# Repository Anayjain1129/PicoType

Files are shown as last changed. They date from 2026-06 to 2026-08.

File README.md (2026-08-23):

# PicoType 
WhatsApp Image 2026-08-19 at 5 43 49 AM













## Zine Page


## Physically Built










### What is this project? 
This is a keyboard made from scratch made by a teenage, made from PCB, CAD to firmware everything! basically this is a keyboard which helps you type things and uses RP2040 and and it sounds thockyy!! 

### How to use it?
1. Assemble the PCB by soldering the Raspberry pi pico, switches and encoder and the OLED display which is on the numpad pcb
2. Plug the MCU (raspberry pi pico) with your computer and make sure the boot button on the MCU is pressed down while you are plugging in the MCU
3. Drag and drop the .uf2 file in the MCU of Raspberry Pi Pico 
4. Do the same things with Xiao rp2040
5. wolla you have everything working!! 

### Why did i made this? 
I made this to learn new skills and learn more about PCBs and do ALOT of CAD the case/CAD of this project took so much time! and the case makes it looks so much awesome! and i have made a separate numpad which can alsop be used as a macropad, you can use it as a full sized keyboard or just as a ANSI-75 Keyboard with a small macropad on your desk! the numpad also have a keychian holder so you can carry it easily too! 

# Features
- EC11 Rotary Encoder - For Volume, Brightness etc
- Oled screen -  To play gifs and notifications
- ANSI-75 Layout
- Raspberry Pi Pico
- Custom Layout
- QMK firmware
- Awesome CAD/cool case design
- Uses RP2040

## Schematics 



## PCB



## 3d PCB



# Case
## Top






## Middle Plate






## Bottom








# 3d view of all parts together







# BOM
| # | Item | Description | Quantity | URL | Total Price (INR) | Total Price (USD) |
|---|---|---|---|-----|:---:|:---:|
| 1 | Numpad PCB | PCB for the Numpad | 5 | N/A | ₹1,845 | $19.53 |
| 2 | PicoType PCB | PCB for the PicoType | 5 | N/A | ₹5,175 | $54.67 |
| 3 | 0.91 Inch OLED | OLED display | 1 | [Link](https://robu.in/product/blue-oled-display-module/) | ₹151 | $1.60 |
| 4 | Switches | The mechanical switches | 11 | [Link](https://neomacro.in/products/gateron-ef-cedar) | ₹1,980 | $20.92 |
| 5 | Rotary Encoder | The Rotary Encoder which can | 1 | [Link](https://robu.in/product/hongyan-ec11h-7ce20p1zy15f7-rotary-encoder-with-push-button-switch-vertical-plug-in-5-pin/) | ₹55 | $0.58 |
| 6 | XIAO RP2040 | MCU to be used for Numpad | 1 | [Link](https://robocraze.com/products/seeed-studio-seeeduino-xiao-samd21-arduino-compatible-board) | ₹645 | $6.81 |
| 7 | Raspberry Pi Pico | MCU to be used for PicoType | 1 | [Link](https://robocraze.com/products/raspberry-pi-pico-h-pico-with-headers-soldered) | ₹525 | $5.55 |
| 8 | Keycaps | Keycaps to put on top of switches | 9 | Self Sourced | N/A | N/A |
| 9 | Case | To put everything together | 1 | Print-Legion | N/A | N/A |
| 10 | Magnets | Magnets to hold the case together | N/A | Self Sourced | N/A | N/A |
| | | | | **Total Cost** | **₹10,376** | **$109.66** |

# Demo Link
https://youtu.be/6P1yl1J2G_w?si=dBfJKUdtHREIIz_N

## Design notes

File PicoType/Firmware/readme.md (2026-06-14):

# picotype

picotype

*A short description of the keyboard/project*

* Keyboard Maintainer: [Anayjain1129](https://github.com/Anayjain1129)
* Hardware Supported: *The PCBs, controllers supported*
* Hardware Availability: *Links to where you can find this hardware*

Make example for this keyboard (after setting up your build environment):

    make picotype:default

Flashing example for this keyboard:

    make picotype:default:flash

See the [build environment setup](https://docs.qmk.fm/#/getting_started_build_tools) and the [make instructions](https://docs.qmk.fm/#/getting_started_make_guide) for more information. Brand new to QMK? Start with our [Complete Newbs Guide](https://docs.qmk.fm/#/newbs).

## Bootloader

Enter the bootloader in 3 ways:

* **Bootmagic reset**: Hold down the key at (0,0) in the matrix (usually the top left key or Escape) and plug in the keyboard
* **Physical reset button**: Briefly press the button on the back of the PCB - some may have pads you must short instead
* **Keycode in layout**: Press the key mapped to `QK_BOOT` if it is available

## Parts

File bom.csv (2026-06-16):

Item | Description | Quantity | URL | Total Price(INR) | Total Price (USD)
Numpad PCB | PCB for the Numpad | 5 | N/A | 1845 | $19.53
PicoType PCB | PCB for the PicoType | 5 | N/A | 5175 | $54.67
0.91 Inch OLED | OLED display | 1 | https://robu.in/product/blue-oled-display-module/ | 151 | $1.60
Switches | The mechanical switces | 11 | https://neomacro.in/products/gateron-ef-cedar | 1980 | $20.92
Rotary Encoder | The Rotary Encode which can | 1 | https://robu.in/product/hongyan-ec11h-7ce20p1zy15f7-rotary-encoder-with-push-button-switch-vertical-plug-in-5-pin/ | 55 | $0.58
XIAO RP2040 | MCU which is fonan be used for numpad | 1 | https://robocraze.com/products/seeed-studio-seeeduino-xiao-samd21-arduino-compatible-board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 | 645 | $6.81
Raspberry Pi Pico | MCU which is fonan be used for PicoType | 1 | https://robocraze.com/products/raspberry-pi-pico-h-pico-with-headers-soldered?_pos=8&_sid=71184d8c2&_ss=r | 525 | $5.55
Keycaps | Keycaps to put on top of switches | 9 | Self Sourced | N/A | N/A
Case | To put eveything together | 1 | Print-Legion | N/A | N/A
Magnets | magnets to hold the case together | N/A | Self Sourced | N/A | N/A
 |  |  | Total Cost: | 10,376 | $109.66

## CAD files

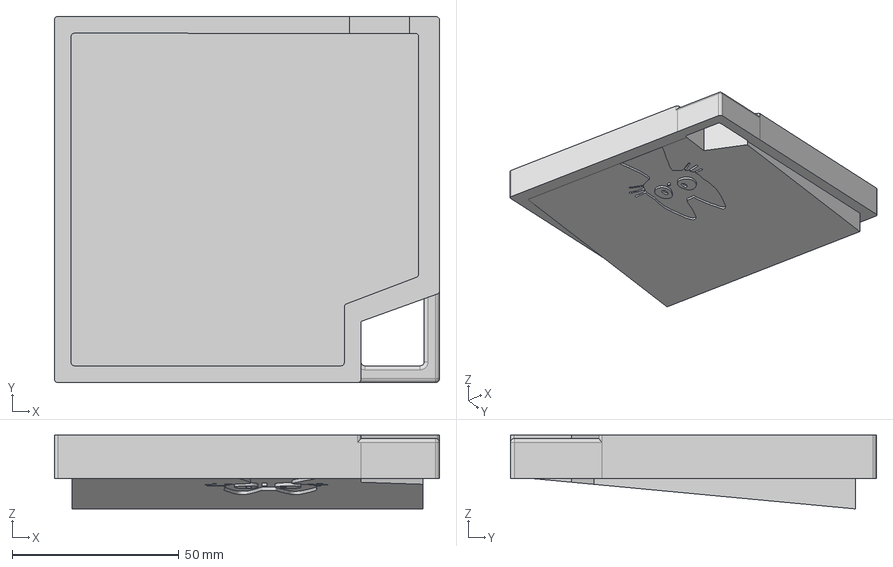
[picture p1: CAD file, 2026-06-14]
numpad/CAD/bottom/bottom.step
115.3 x 109.6 x 22.1 mm

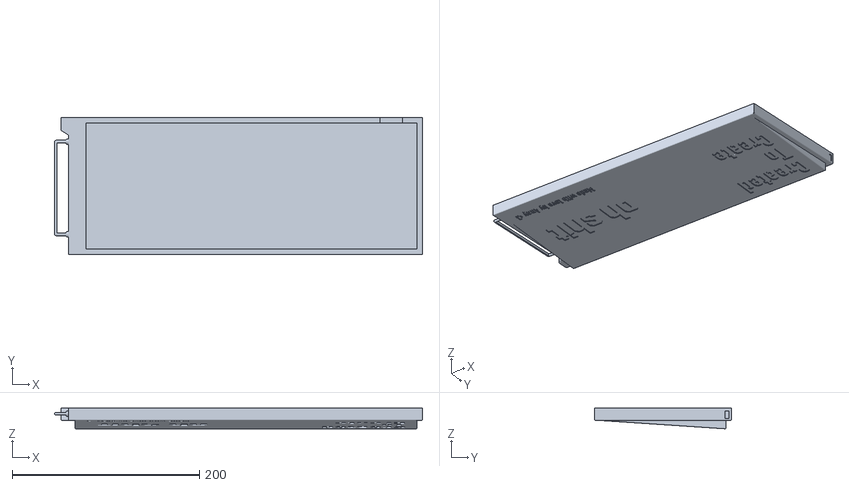
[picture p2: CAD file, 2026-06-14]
PicoType/CAD/bottom/bottom.stl
393.0 x 146.7 x 22.0

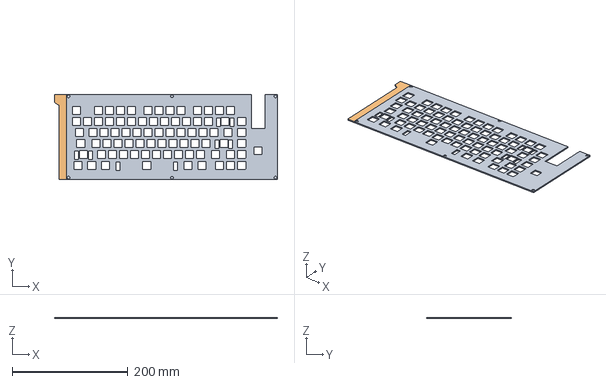
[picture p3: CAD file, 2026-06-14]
PicoType/CAD/middle/middle.step
386.0 x 147.3 x 2.00 mm

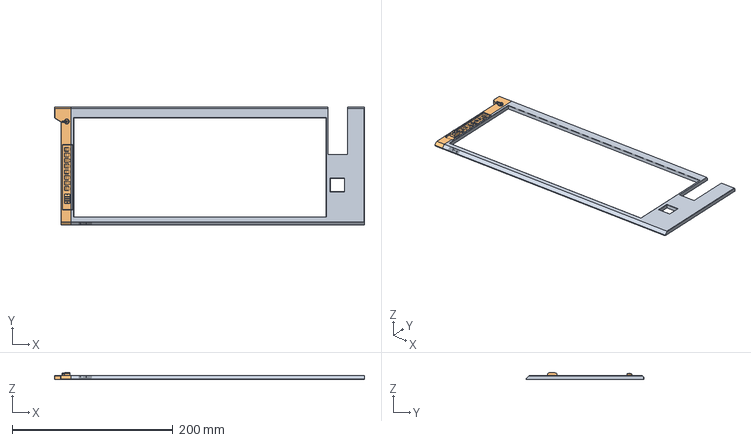
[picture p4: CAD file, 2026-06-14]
PicoType/CAD/top/top.step
386.0 x 147.3 x 9.00 mm

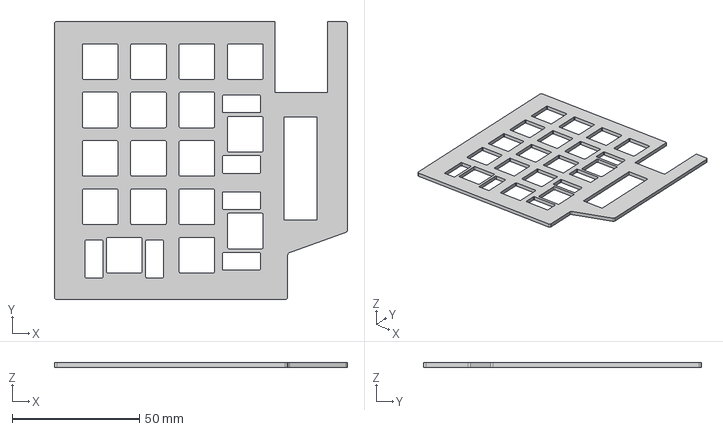
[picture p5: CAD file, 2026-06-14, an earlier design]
numpad/CAD/middle/middle.step
115.3 x 109.6 x 2.00 mm

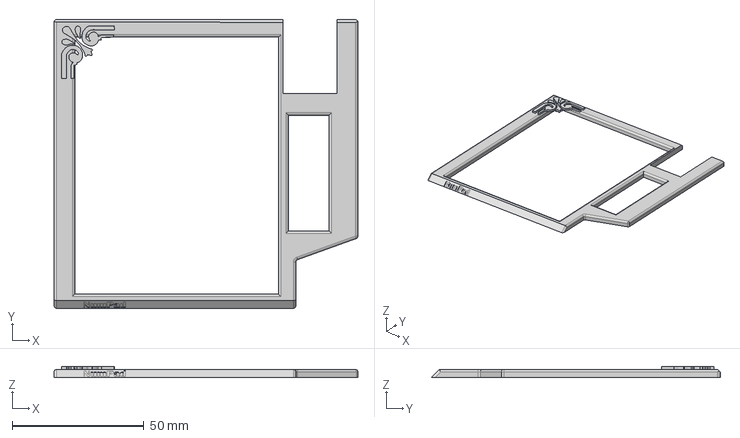
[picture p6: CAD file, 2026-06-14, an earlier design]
numpad/CAD/top/top.step
115.3 x 109.6 x 4.00 mm

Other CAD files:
PicoType/CAD/bottom/bttom.step
PicoType/Production/CAD/bttom.step
Assembly/keyboard.f3z
Assembly/numpad.f3z
PicoType/CAD/bottom/bottom.f3d
PicoType/CAD/middle/middle.f3d
PicoType/CAD/middle/middle.stl
PicoType/CAD/top/top.f3d
PicoType/CAD/top/top.stl
PicoType/Production/CAD/middle.stl
PicoType/Production/CAD/top.stl
numpad/CAD/bottom/bottom.f3d
numpad/CAD/bottom/bottom.stl
numpad/CAD/middle/middle.f3d
numpad/CAD/middle/middle.stl
numpad/CAD/top/top.f3d
numpad/CAD/top/top.stl
numpad/Production/CAD/bottom.stl
numpad/Production/CAD/middle.stl
numpad/Production/CAD/top.stl

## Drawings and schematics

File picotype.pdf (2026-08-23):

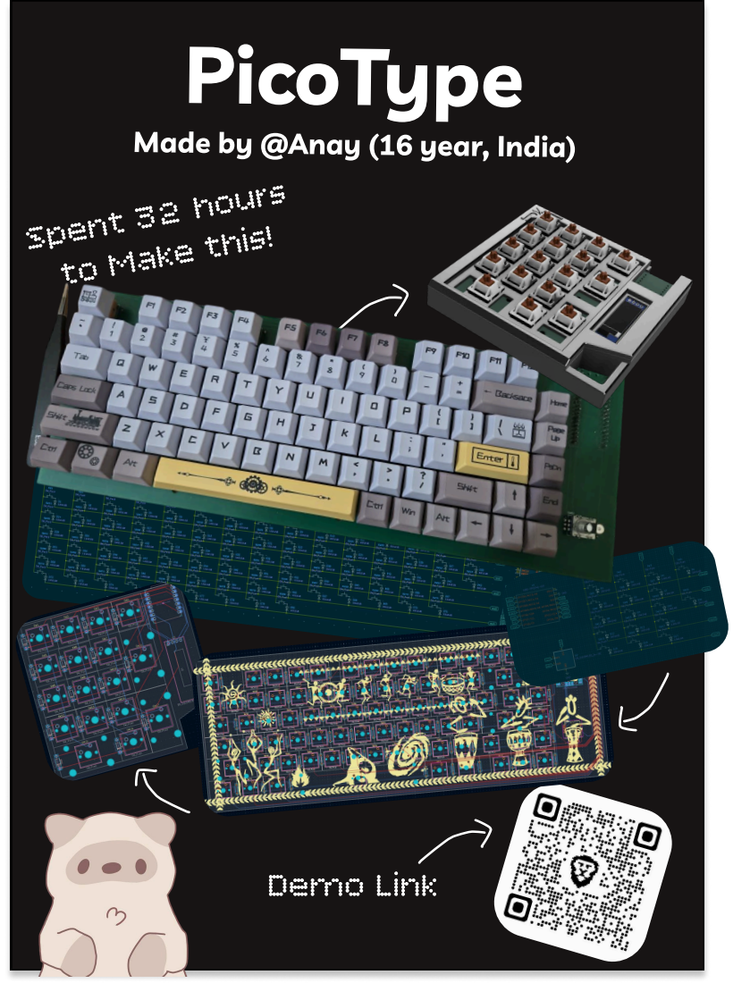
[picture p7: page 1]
Spent 32 hours; PicoType; Demo Link

Made by @Anay (16 year, India)

to Make this!

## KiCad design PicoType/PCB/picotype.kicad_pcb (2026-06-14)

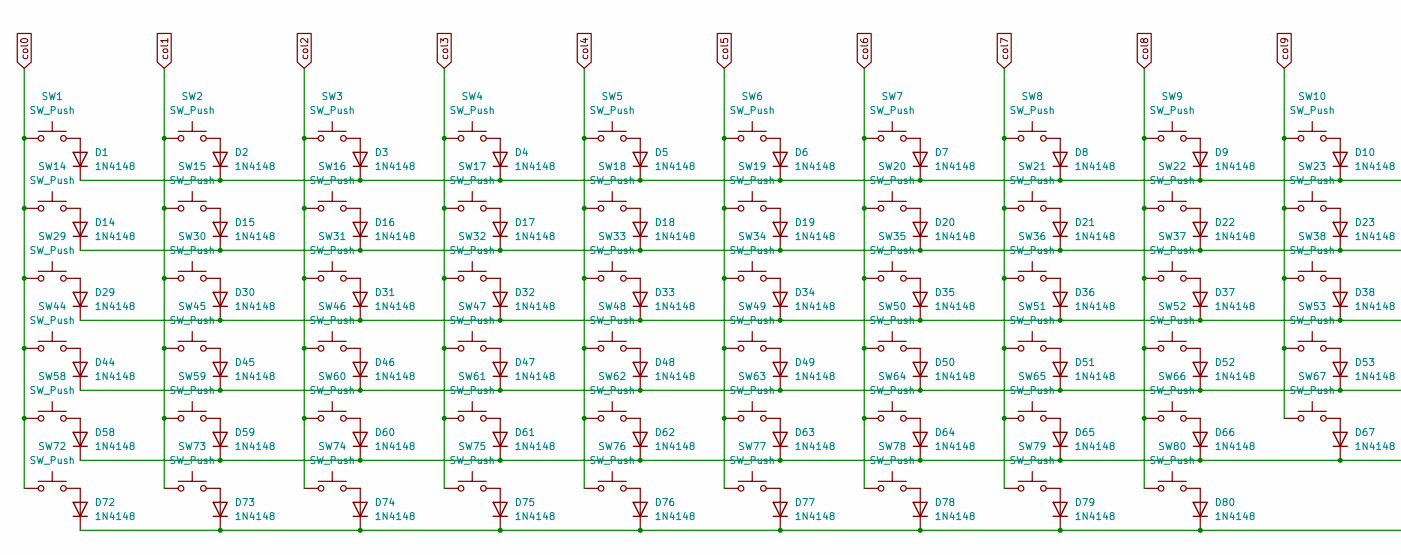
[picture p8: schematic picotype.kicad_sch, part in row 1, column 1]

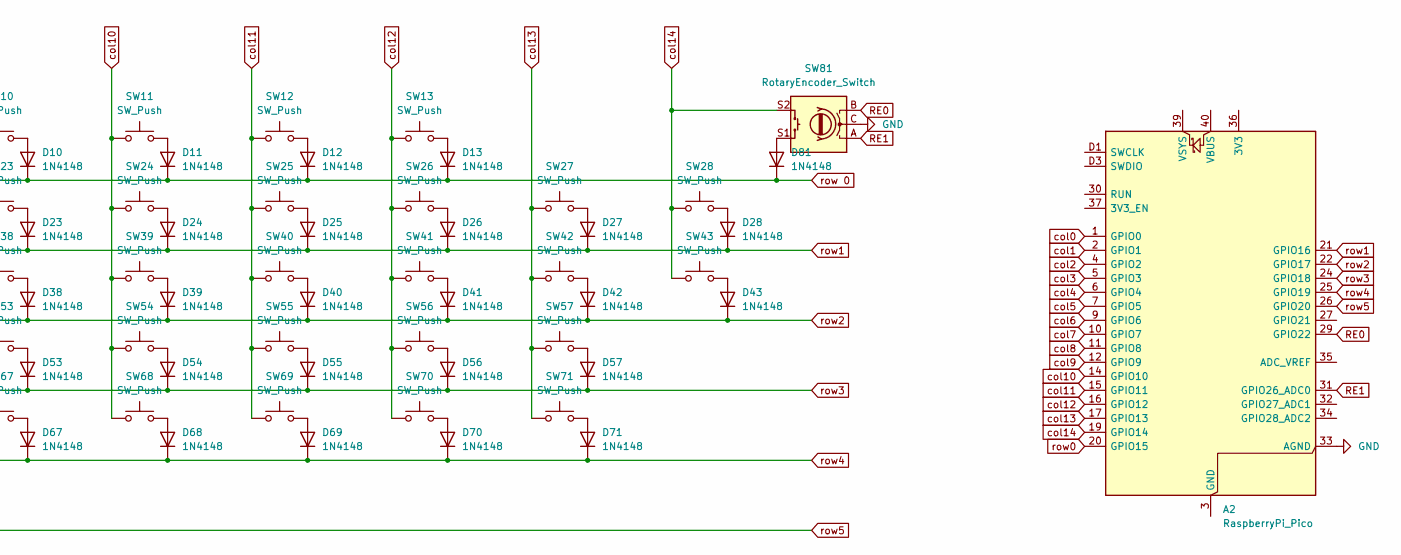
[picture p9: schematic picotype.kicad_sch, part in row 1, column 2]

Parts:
A2: RaspberryPi_Pico; RaspberryPi_Pico_SMD_HandSolder
D1, D2, D3, D4, D5, D6, D7, D8, D9, D10, D11, D12, D13, D14, D15, D16, D17, D18, D19, D20, D21, D22, D23, D24, D25, D26, D27, D28, D29, D30, D31, D32, D33, D34, D35, D36, D37, D38, D39, D40, D41, D42, D43, D44, D45, D46, D47, D48, D49, D50, D51, D52, D53, D54, D55, D56, D57, D58, D59, D60, D61, D62, D63, D64, D65, D66, D67, D68, D69, D70, D71, D72, D73, D74, D75, D76, D77, D78, D79, D80, D81: 1N4148; D_DO-35_SOD27_P7.62mm_Horizontal
SW1, SW2, SW3, SW4, SW5, SW6, SW7, SW8, SW9, SW10, SW11, SW12, SW13, SW14, SW15, SW16, SW17, SW18, SW19, SW20, SW21, SW22, SW23, SW24, SW25, SW26, SW28, SW30, SW31, SW32, SW33, SW34, SW35, SW36, SW37, SW38, SW39, SW40, SW41, SW43, SW45, SW46, SW47, SW48, SW49, SW50, SW51, SW52, SW53, SW54, SW55, SW57, SW59, SW60, SW61, SW62, SW63, SW64, SW65, SW66, SW67, SW68, SW70, SW71, SW78, SW79, SW80: SW_Push; SW_Cherry_MX_1.00u_PCB
SW27: SW_Push; SW_Cherry_MX_2.00u_PCB
SW29, SW42: SW_Push; SW_Cherry_MX_1.50u_PCB
SW44, SW69: SW_Push; SW_Cherry_MX_1.75u_PCB
SW56, SW58: SW_Push; SW_Cherry_MX_2.25u_PCB
SW72, SW73, SW74, SW76, SW77: SW_Push; SW_Cherry_MX_1.25u_PCB
SW75: SW_Push; SW_Cherry_MX_6.25u_PCB
SW81: RotaryEncoder_Switch; RotaryEncoder_Alps_EC12E-Switch_Vertical_H20mm_CircularMoun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

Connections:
GND: A2.33 (AGND), SW81.C
unnamed: A2.3 (GND), A2.8 (GND), A2.13 (GND), A2.18 (GND), A2.23 (GND), A2.28 (GND), A2.38 (GND), A2.D2 (GND)
unnamed: D1.2 (A), SW1.2
unnamed: D2.2 (A), SW2.2
unnamed: D3.2 (A), SW3.2
unnamed: D4.2 (A), SW4.2
unnamed: D5.2 (A), SW5.2
unnamed: D6.2 (A), SW6.2
unnamed: D7.2 (A), SW7.2
unnamed: D8.2 (A), SW8.2
unnamed: D9.2 (A), SW9.2
unnamed: D10.2 (A), SW10.2
unnamed: D11.2 (A), SW11.2
unnamed: D12.2 (A), SW12.2
unnamed: D13.2 (A), SW13.2
unnamed: D14.2 (A), SW14.2
unnamed: D15.2 (A), SW15.2
unnamed: D16.2 (A), SW16.2
unnamed: D17.2 (A), SW17.2
unnamed: D18.2 (A), SW18.2
unnamed: D19.2 (A), SW19.2
unnamed: D20.2 (A), SW20.2
unnamed: D21.2 (A), SW21.2
unnamed: D22.2 (A), SW22.2
unnamed: D23.2 (A), SW23.2
unnamed: D24.2 (A), SW24.2
unnamed: D25.2 (A), SW25.2
unnamed: D26.2 (A), SW26.2
unnamed: D27.2 (A), SW27.2
unnamed: D28.2 (A), SW28.2
unnamed: D29.2 (A), SW29.2
unnamed: D30.2 (A), SW30.2
unnamed: D31.2 (A), SW31.2
unnamed: D32.2 (A), SW32.2
unnamed: D33.2 (A), SW33.2
unnamed: D34.2 (A), SW34.2
unnamed: D35.2 (A), SW35.2
unnamed: D36.2 (A), SW36.2
unnamed: D37.2 (A), SW37.2
unnamed: D38.2 (A), SW38.2
unnamed: D39.2 (A), SW39.2
unnamed: D40.2 (A), SW40.2
unnamed: D41.2 (A), SW41.2
unnamed: D42.2 (A), SW42.2
unnamed: D43.2 (A), SW43.2
unnamed: D44.2 (A), SW44.2
unnamed: D45.2 (A), SW45.2
unnamed: D46.2 (A), SW46.2
unnamed: D47.2 (A), SW47.2
unnamed: D48.2 (A), SW48.2
unnamed: D49.2 (A), SW49.2
unnamed: D50.2 (A), SW50.2
unnamed: D51.2 (A), SW51.2
unnamed: D52.2 (A), SW52.2
unnamed: D53.2 (A), SW53.2
unnamed: D54.2 (A), SW54.2
unnamed: D55.2 (A), SW55.2
unnamed: D56.2 (A), SW56.2
unnamed: D57.2 (A), SW57.2
unnamed: D58.2 (A), SW58.2
unnamed: D59.2 (A), SW59.2
unnamed: D60.2 (A), SW60.2
unnamed: D61.2 (A), SW61.2
unnamed: D62.2 (A), SW62.2
unnamed: D63.2 (A), SW63.2
unnamed: D64.2 (A), SW64.2
unnamed: D65.2 (A), SW65.2
unnamed: D66.2 (A), SW66.2
unnamed: D67.2 (A), SW67.2
unnamed: D68.2 (A), SW68.2
unnamed: D69.2 (A), SW69.2
unnamed: D70.2 (A), SW70.2
unnamed: D71.2 (A), SW71.2
unnamed: D72.2 (A), SW72.2
unnamed: D73.2 (A), SW73.2
unnamed: D74.2 (A), SW74.2
unnamed: D75.2 (A), SW75.2
unnamed: D76.2 (A), SW76.2
unnamed: D77.2 (A), SW77.2
unnamed: D78.2 (A), SW78.2
unnamed: D79.2 (A), SW79.2
unnamed: D80.2 (A), SW80.2
unnamed: D81.2 (A), SW81.S1
RE0: A2.29 (GPIO22), SW81.B
RE1: A2.31 (GPIO26_ADC0), SW81.A
col0: A2.1 (GPIO0), SW1.1, SW14.1, SW29.1, SW44.1, SW58.1, SW72.1
col1: A2.2 (GPIO1), SW2.1, SW15.1, SW30.1, SW45.1, SW59.1, SW73.1
col2: A2.4 (GPIO2), SW3.1, SW16.1, SW31.1, SW46.1, SW60.1, SW74.1
col3: A2.5 (GPIO3), SW4.1, SW17.1, SW32.1, SW47.1, SW61.1, SW75.1
col4: A2.6 (GPIO4), SW5.1, SW18.1, SW33.1, SW48.1, SW62.1, SW76.1
col5: A2.7 (GPIO5), SW6.1, SW19.1, SW34.1, SW49.1, SW63.1, SW77.1
col6: A2.9 (GPIO6), SW7.1, SW20.1, SW35.1, SW50.1, SW64.1, SW78.1
col7: A2.10 (GPIO7), SW8.1, SW21.1, SW36.1, SW51.1, SW65.1, SW79.1
col8: A2.11 (GPIO8), SW9.1, SW22.1, SW37.1, SW52.1, SW66.1, SW80.1
col9: A2.12 (GPIO9), SW10.1, SW23.1, SW38.1, SW53.1, SW67.1
col10: A2.14 (GPIO10), SW11.1, SW24.1, SW39.1, SW54.1, SW68.1
col11: A2.15 (GPIO11), SW12.1, SW25.1, SW40.1, SW55.1, SW69.1
col12: A2.16 (GPIO12), SW13.1, SW26.1, SW41.1, SW56.1, SW70.1
col13: A2.17 (GPIO13), SW27.1, SW42.1, SW57.1, SW71.1
col14: A2.19 (GPIO14), SW28.1, SW43.1, SW81.S2
row0: A2.20 (GPIO15)
row1: A2.21 (GPIO16), D14.1 (K), D15.1 (K), D16.1 (K), D17.1 (K), D18.1 (K), D19.1 (K), D20.1 (K), D21.1 (K), D22.1 (K), D23.1 (K), D24.1 (K), D25.1 (K), D26.1 (K), D27.1 (K), D28.1 (K)
row2: A2.22 (GPIO17), D29.1 (K), D30.1 (K), D31.1 (K), D32.1 (K), D33.1 (K), D34.1 (K), D35.1 (K), D36.1 (K), D37.1 (K), D38.1 (K), D39.1 (K), D40.1 (K), D41.1 (K), D42.1 (K), D43.1 (K)
row3: A2.24 (GPIO18), D44.1 (K), D45.1 (K), D46.1 (K), D47.1 (K), D48.1 (K), D49.1 (K), D50.1 (K), D51.1 (K), D52.1 (K), D53.1 (K), D54.1 (K), D55.1 (K), D56.1 (K), D57.1 (K)
row4: A2.25 (GPIO19), D58.1 (K), D59.1 (K), D60.1 (K), D61.1 (K), D62.1 (K), D63.1 (K), D64.1 (K), D65.1 (K), D66.1 (K), D67.1 (K), D68.1 (K), D69.1 (K), D70.1 (K), D71.1 (K)
row5: A2.26 (GPIO20), D72.1 (K), D73.1 (K), D74.1 (K), D75.1 (K), D76.1 (K), D77.1 (K), D78.1 (K), D79.1 (K), D80.1 (K)
row 0: D1.1 (K), D2.1 (K), D3.1 (K), D4.1 (K), D5.1 (K), D6.1 (K), D7.1 (K), D8.1 (K), D9.1 (K), D10.1 (K), D11.1 (K), D12.1 (K), D13.1 (K), D81.1 (K)

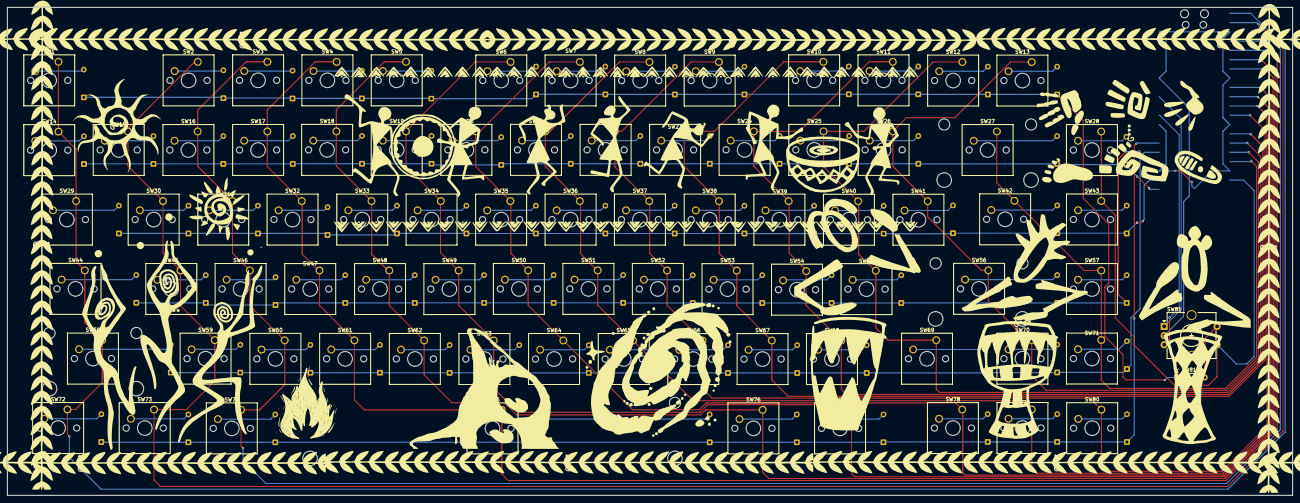
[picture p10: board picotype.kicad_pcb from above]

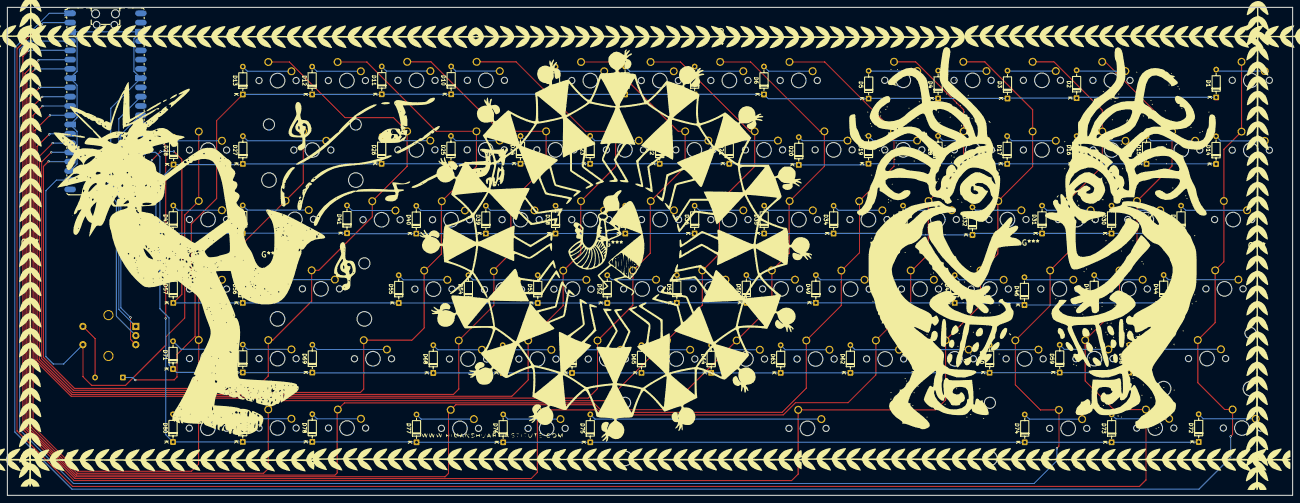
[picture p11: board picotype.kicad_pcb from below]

Board: 2 copper layers, 352.2 x 133.7 mm, 163 parts (81 on the bottom side), 106 nets.
